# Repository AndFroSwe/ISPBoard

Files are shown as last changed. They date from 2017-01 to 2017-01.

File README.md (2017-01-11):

# ISPBoard

This repo contains a project with a programming board for Atmel 28 DIP that can
be programmed using a 6-pin JTAG port (ISP). It is designed specifically for use
with ATmega 328P dip package.

# Software
For this project, the following software is used:

- KiCad
- Solid Edge

# Revisions

## Rev 1
External power needed. Test ports for leds, buttons and 2 pins from each pin
register.

## Rev 2
__Moved to this separate repo.__ 

Added battery power via a 9-5V DCDC converter. Improved layout. Added a port for
USART output. Added a 3D-printed case for the PCB.

# Future (potential) improvements

- USART output via FTDI chip to USB contact.

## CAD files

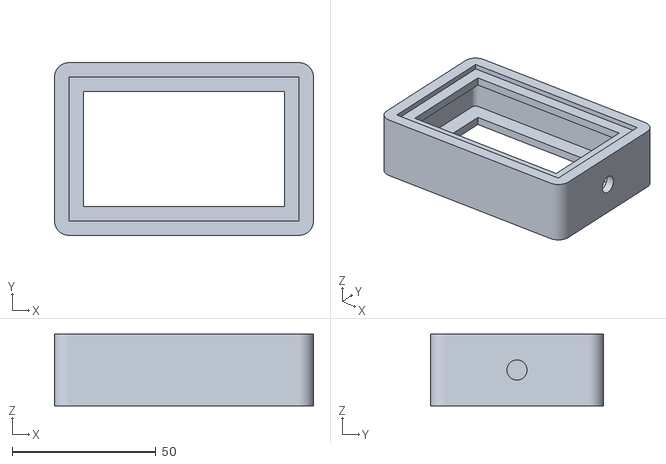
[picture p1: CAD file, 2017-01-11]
KiCad/CAD/Board_case.stl
90.0 x 60.0 x 25.0

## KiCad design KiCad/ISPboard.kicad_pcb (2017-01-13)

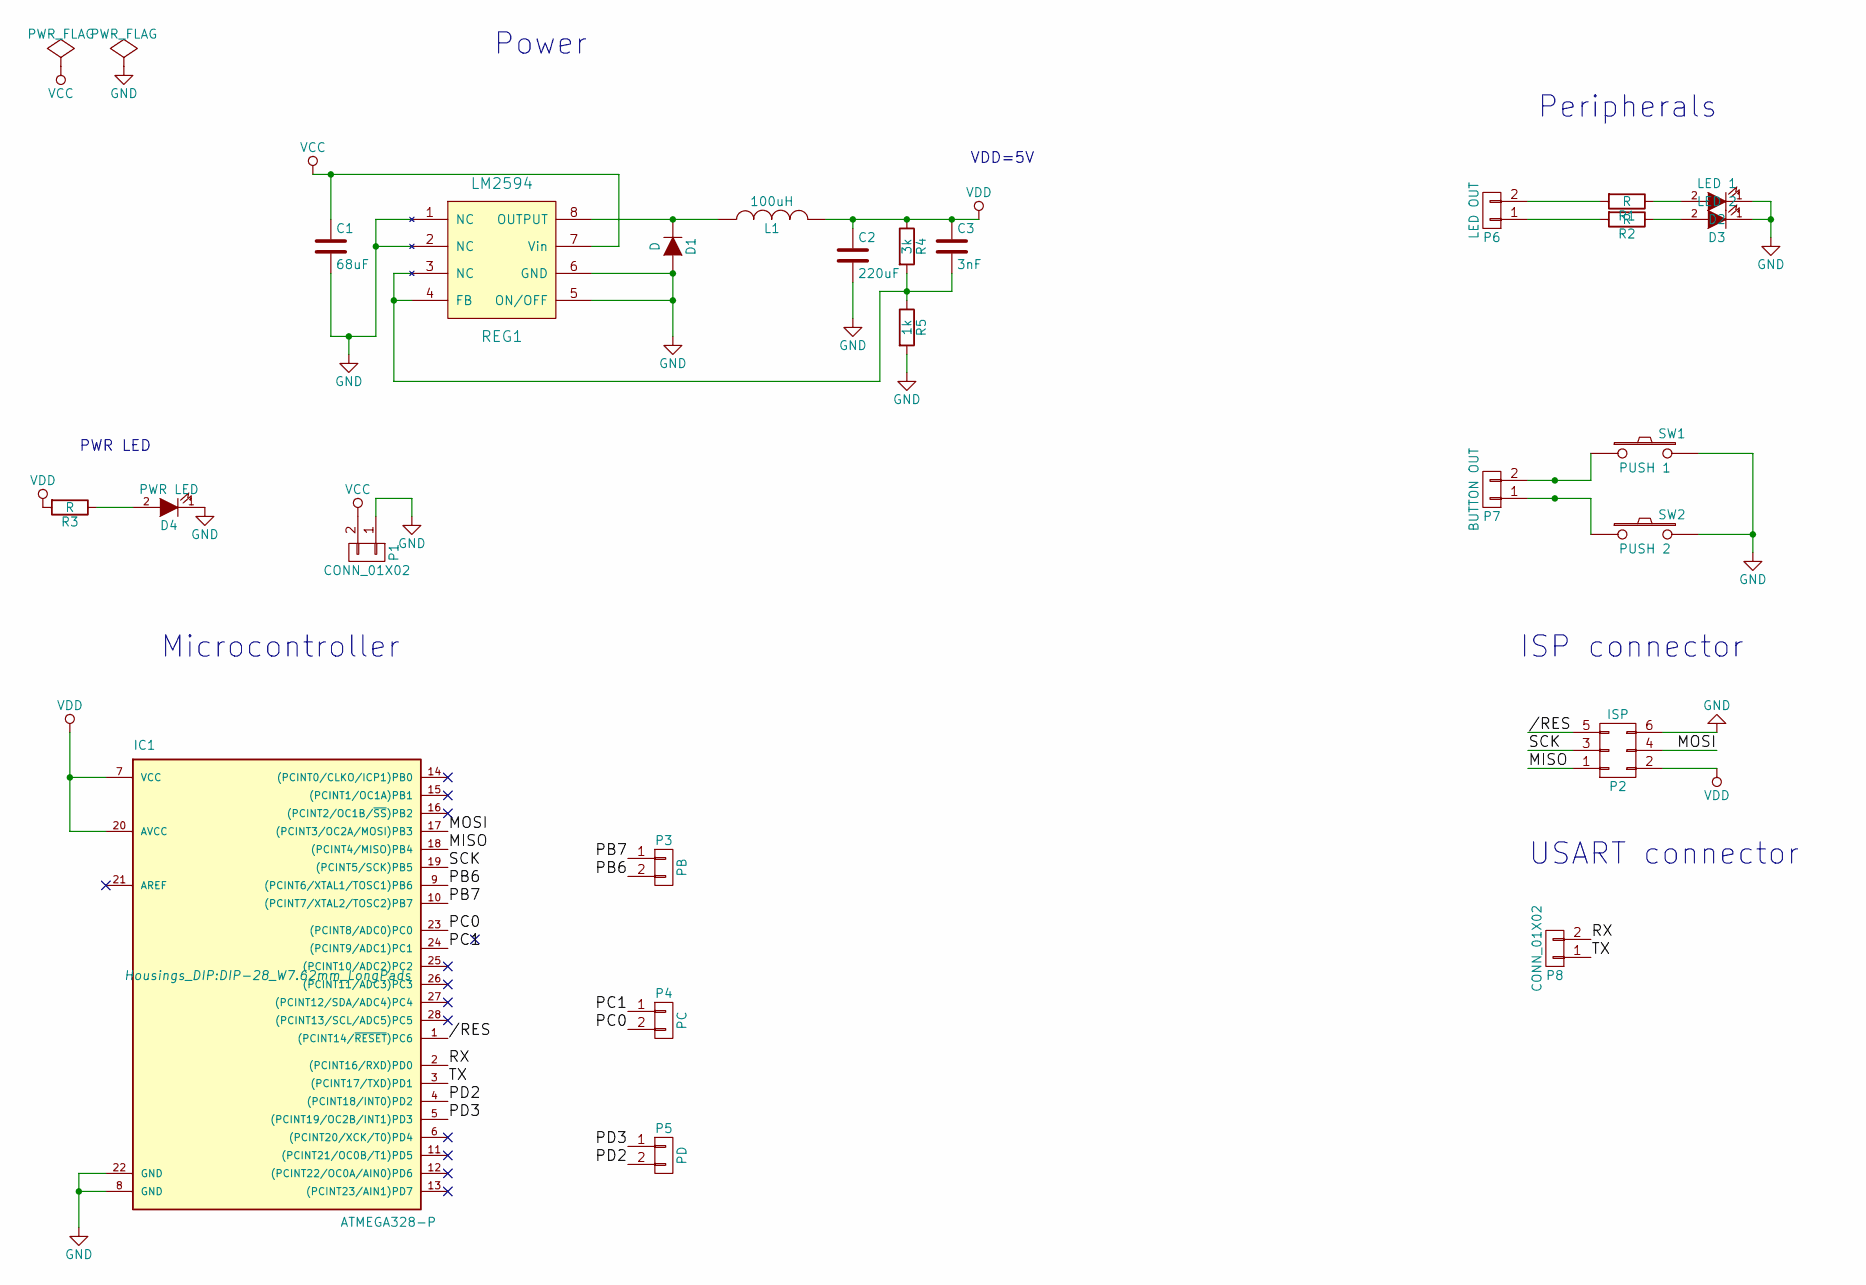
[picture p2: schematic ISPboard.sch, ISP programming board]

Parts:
C1: 68uF; c_elec_4x4.5
C2: 220uF; c_elec_4x4.5
C3: 3nF; C_0805_HandSoldering
D1: D; SMB_Handsoldering
D2: LED 1; LED-5MM
D3: LED 2; LED-5MM
D4: PWR LED; LED-5MM
IC1: ATMEGA328-P; DIP-28_W7.62mm_LongPads
L1: 100uH; Choke_SMD_Wuerth-WE-PD2-Typ-L
P1: CONN_01X02; Socket_Strip_Straight_1x02
P2: ISP; Socket_Strip_Straight_2x03
P3: PB; Molex_KK-6410-02_02x2.54mm_Straight
P4: PC; Molex_KK-6410-02_02x2.54mm_Straight
P5: PD; Molex_KK-6410-02_02x2.54mm_Straight
P6: LED OUT; Molex_KK-6410-02_02x2.54mm_Straight
P7: BUTTON OUT; Molex_KK-6410-02_02x2.54mm_Straight
P8: CONN_01X02; Molex_KK-6410-02_02x2.54mm_Straight
R1, R2, R3: R; R_1206_HandSoldering
R4: 3k; R_1206_HandSoldering
R5: 1k; R_1206_HandSoldering
REG1: LM2594; SOIC-8_3.9x4.9mm_Pitch1.27mm
SW1: PUSH 1; SW_PUSH_6mm
SW2: PUSH 2; SW_PUSH_6mm

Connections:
//RES: IC1.1 ((PCINT14/~RESET~)PC6), P2.5
/MISO: IC1.18 ((PCINT4/MISO)PB4), P2.1
/MOSI: IC1.17 ((PCINT3/OC2A/MOSI)PB3), P2.4
/PB6: IC1.9 ((PCINT6/XTAL1/TOSC1)PB6), P3.2
/PB7: IC1.10 ((PCINT7/XTAL2/TOSC2)PB7), P3.1
/PC0: IC1.23 ((PCINT8/ADC0)PC0), P4.2
/PC1: IC1.24 ((PCINT9/ADC1)PC1), P4.1
/PD2: IC1.4 ((PCINT18/INT0)PD2), P5.2
/PD3: IC1.5 ((PCINT19/OC2B/INT1)PD3), P5.1
/RX: IC1.2 ((PCINT16/RXD)PD0), P8.2
/SCK: IC1.19 ((PCINT5/SCK)PB5), P2.3
/TX: IC1.3 ((PCINT17/TXD)PD1), P8.1
GND: C1.2, C2.2, D1.2 (A), D2.1 (K), D3.1 (K), D4.1 (K), IC1.8 (GND), IC1.22 (GND), P1.1, P2.6, R5.2, REG1.1 (NC), REG1.2 (NC), REG1.5 (ON/OFF), REG1.6 (GND), SW1.2, SW2.2
unnamed: C3.2, R4.2, R5.1, REG1.3 (NC), REG1.4 (FB)
unnamed: D1.1 (K), L1.1, REG1.8 (OUTPUT)
unnamed: D2.2 (A), R1.1
unnamed: D3.2 (A), R2.1
unnamed: D4.2 (A), R3.1
unnamed: P6.1, R2.2
unnamed: P6.2, R1.2
unnamed: P7.1, SW2.1
unnamed: P7.2, SW1.1
VCC: C1.1, P1.2, REG1.7 (Vin)
VDD: C2.1, C3.1, IC1.7 (VCC), IC1.20 (AVCC), L1.2, P2.2, R3.2, R4.1

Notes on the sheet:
Microcontroller
Power
ISP connector
Peripherals
PWR LED
VDD=5V
USART connector

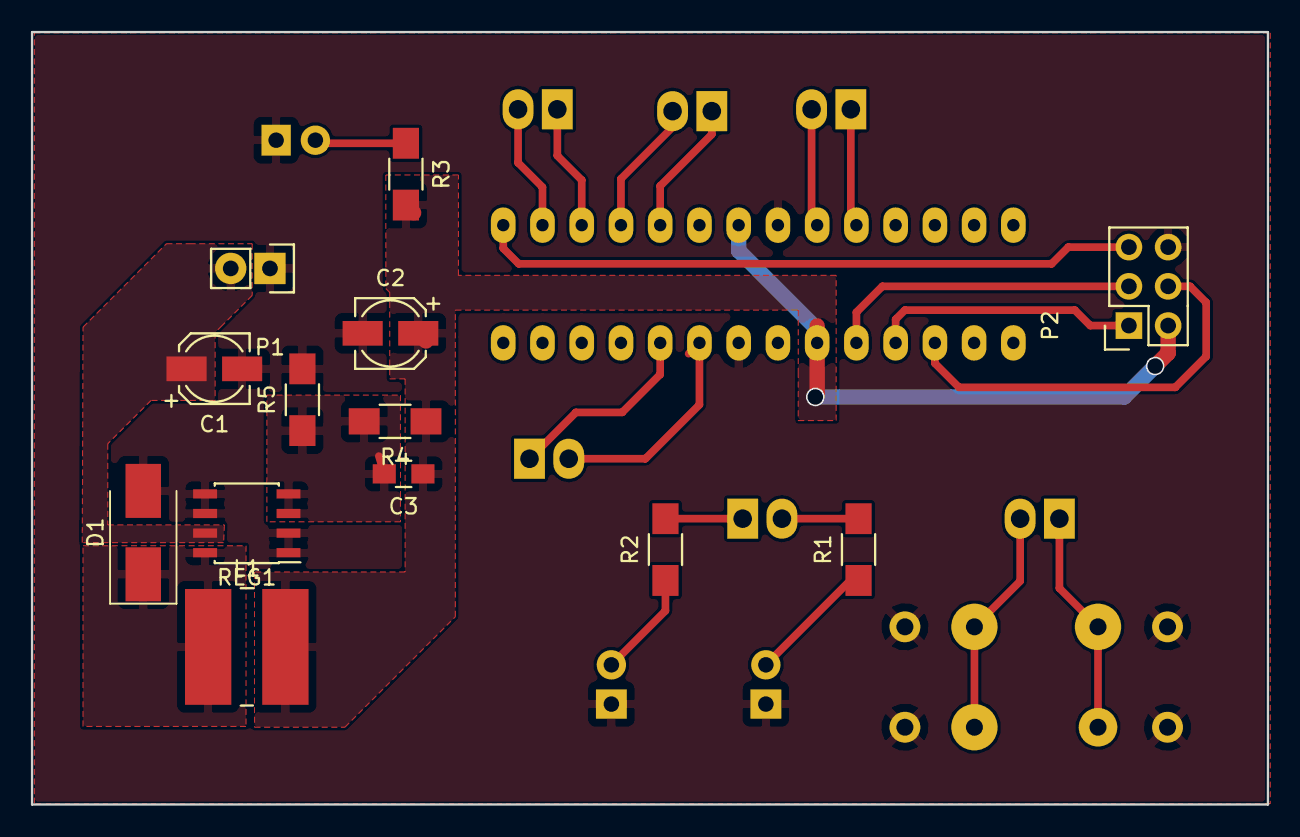
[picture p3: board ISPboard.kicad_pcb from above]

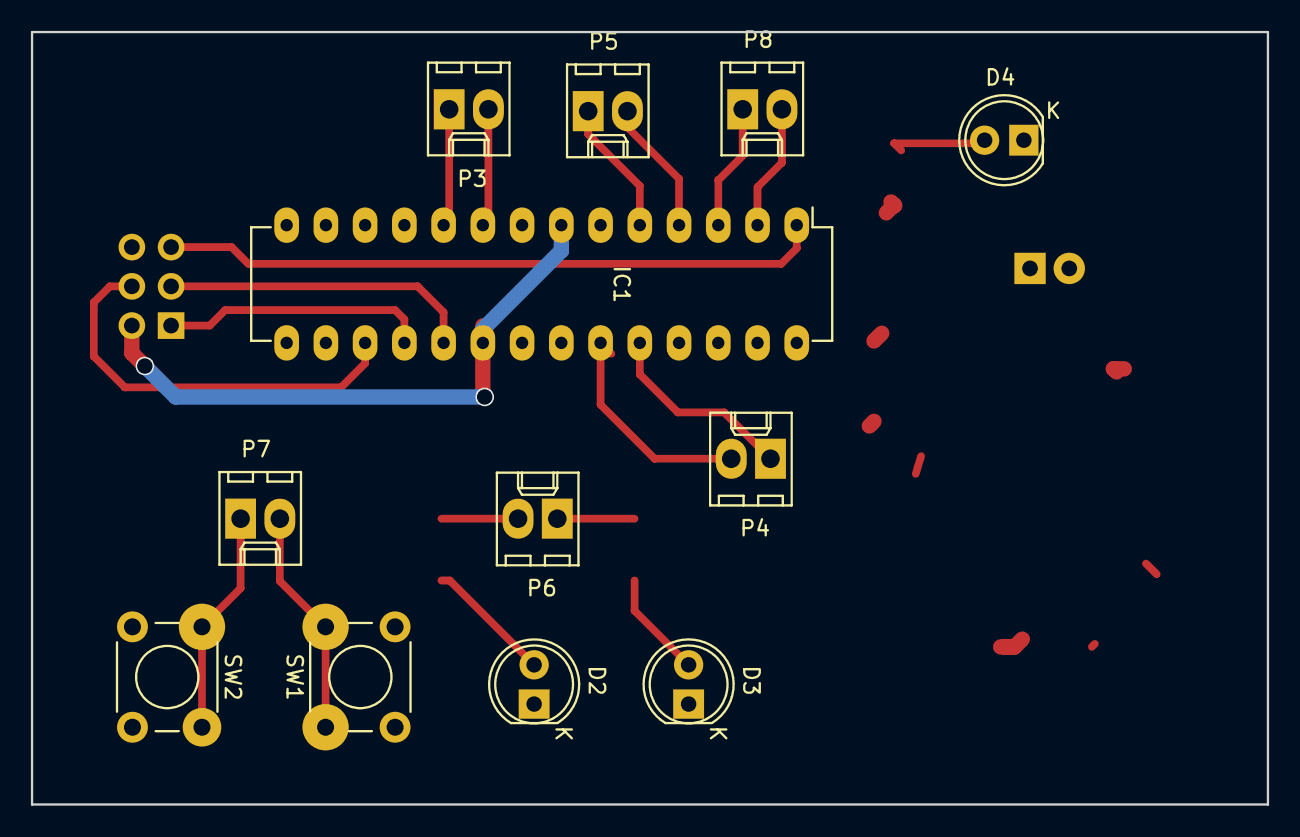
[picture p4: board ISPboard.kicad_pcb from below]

Board: 2 copper layers, 80.0 x 50.0 mm, 25 parts (12 on the bottom side), 24 nets.

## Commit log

2017-01-11 Initial commit to new repo. Made a proper README and moved all files to this repo
    [Board_case.stl, ISPboard.kicad_pcb, ISPboard.sch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]
2017-01-13 Changed layout to have filled zones for input regulator
    [ISPboard.kicad_pcb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]
